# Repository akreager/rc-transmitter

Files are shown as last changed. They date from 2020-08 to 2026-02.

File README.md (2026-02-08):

# RC Transmitter
Open-source design and code for a 3D-printed pistol-grip RC transmitter.

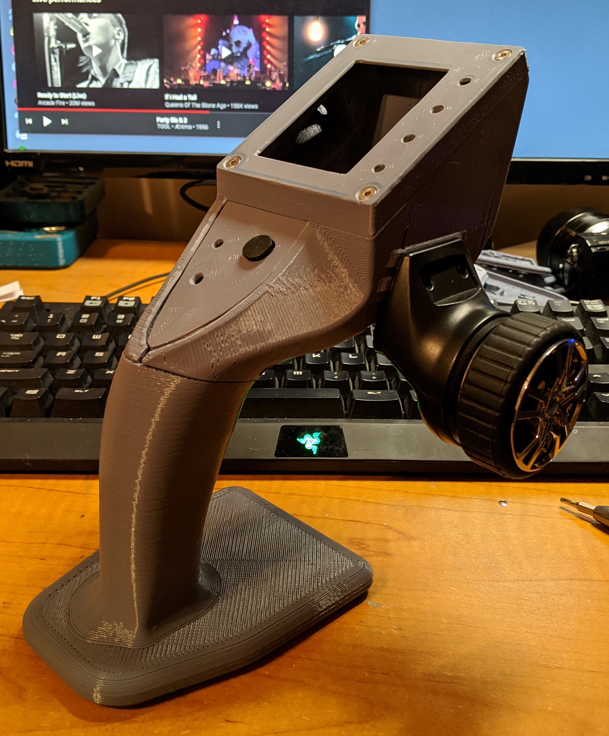
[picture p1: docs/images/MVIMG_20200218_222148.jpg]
Front


## Overview
A general-purpose RC transmitter designed to control multiple vehicles by swapping configuration profiles. Currently used with an RC snowblower and an engineering test rover.

### Features
- **Wireless control** via nRF24L01+ with bidirectional telemetry (acknowledge payloads)
- **Touchscreen UI** on a 240x320 TFT with resistive touch input
- **Live telemetry** display: battery voltage, board temperatures, motor currents
- **Motor stop** (M-Stop) soft button on the touchscreen
- **Joystick input** for throttle and steering

### Planned
- Joystick calibration via touchscreen UI
- Physical button matrix (multiplexed)
- SD card configuration profiles for multi-vehicle support
- Settings/setup menu

## Hardware

### Transmitter
- MCU with dual SPI buses (currently Teensy 4.1)
- [Adafruit 2.8" TFT Touch Breakout](https://www.adafruit.com/product/1770) — ILI9341 display with resistive touchscreen (SPI1)
- nRF24L01+ radio module (SPI0)
- Analog joystick (steering + throttle)

### Receiver ([Rover Test Platform](https://github.com/akreager/roverTest))
- Arduino Mega
- nRF24L01+ radio module
- Basicmicro RoboClaw motor controller

## Project Structure
```
RC Transmitter/
├── main/                 # Transmitter firmware (Arduino IDE)
│   ├── main.ino          # Setup, loop, radio, global state
│   ├── config.h          # Pin assignments, constants, shared types
│   ├── touchInput.ino    # Touch state machine
│   ├── screenManager.ino # Screen transitions and button management
│   └── drawScreens.ino   # Screen drawing and UI updates
├── test_sketches/        # Standalone test/reference sketches
├── stl/                  # 3D printed enclosure files
├── docs/                 # Documentation and images
├── LICENSE               # GPLv3
└── README.md
```

## Pin Assignments (Teensy 4.1)

Active pin mapping for the current build. Also maintained in [Google Sheets](https://docs.google.com/spreadsheets/d/1aVeEQQCFw7_oekkrW9wztb_qrHcS88uQesicZp7ygn0/edit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).

### Display & Touch (SPI1)
| Function | Pin  | Notes |
|---|---|---|
| CLK | D27  | SPI1 clock |
| MISO | D1 | SPI1 data in |
| MOSI | D26  | SPI1 data out |
| TFT CS | D0 | Display chip select |
| TFT DC | D2 | Display data/command |
| Backlight| D3 | PWM brightness control  |
| Touch Y+ | D24  | Analog (A10) |
| Touch X- | D25  | Analog (A11) |
| Touch X+ | D28  | Digital |
| Touch Y- | D29  | Digital |

### Radio (SPI0)
| Function | Pin  | Notes |
|---|---|---|
| SCK | D13  | SPI0 clock (default) |
| MISO | D12  | SPI0 data in (default)  |
| MOSI | D11  | SPI0 data out (default) |
| CE | D9 | |
| CSN | D10  | |

### Inputs
| Function  | Pin  | Notes |
|---|---|---|
| Steering  | D14  | Analog (A0) — wheel input |
| Throttle  | D15  | Analog (A1) — trigger input |
| Joystick X| D17  | Analog (A3) — e.g. chute aim L/R  |
| Joystick Y| D16  | Analog (A2) — e.g. chute aim U/D  |

### Button Matrix (planned)
| Function | Pin  | Notes |
|---|---|---|
| Row A | D30  | Digital |
| Row B | D31  | Digital |
| Row C | D32  | Digital |
| Row D | D33  | Digital |
| Col 1 | D34  | Digital |
| Col 2 | D35  | Digital |

## CAD Source
3D design for the transmitter enclosure is on [OnShape](https://cad.onshape.com/documents/a59ab4c30cdb2f94f953abb2/v/0076fda3a5d6eca29f873ec9/e/06b2695cd32d304990fa8f74).

## Dependencies
Install via Arduino IDE Library Manager:
- [RF24](https://github.com/tmrh20/RF24/) (TMRh20 fork)
- [Adafruit GFX Library](https://github.com/adafruit/Adafruit-GFX-Library)
- [Adafruit ILI9341](https://github.com/adafruit/Adafruit_ILI9341)
- [Adafruit BusIO](https://github.com/adafruit/Adafruit_BusIO)

Bundled with the Teensy board package:
- TouchScreen — included in `{teensy_package}/libraries/TouchScreen`, API-compatible with [Adafruit TouchScreen](https://github.com/adafruit/Adafruit_TouchScreen)

Receiver also requires:
- [RoboClaw Arduino Library](https://github.com/basicmicro/roboclaw_arduino_library)

## Development
This project is developed with assistance from Claude (Anthropic), used for code architecture, refactoring, and documentation.

## License
This project is licensed under the GNU General Public License v3.0 — see [LICENSE](LICENSE) for details.

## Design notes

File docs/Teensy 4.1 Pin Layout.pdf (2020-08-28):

# Teensy 4.1

8/28/2020

Pin (42) | Pins Available Analog In UART I2C SPI PWM Out (18) (8) (3) (3) (27) | Pins Used (66.7%) NRF24 Touch TFT I/O (5/6) (10/11) (13/13)

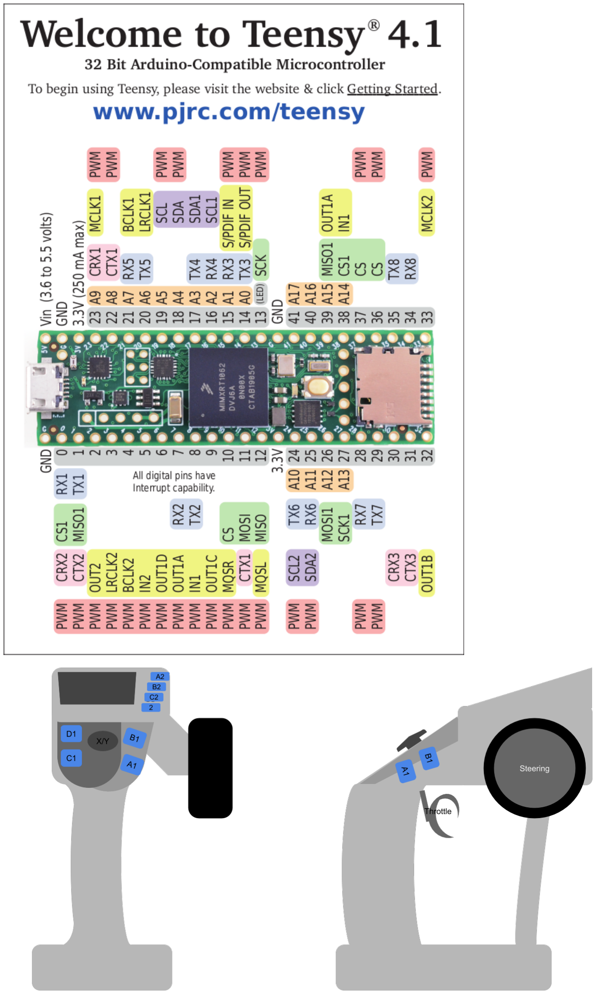
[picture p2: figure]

D0 D1 D2 D3 | RX1 CS1 PWM TX1 MISO1 PWM PWM PWM | TFT_CS MISO D/C LITE
D4 D5 D6 D7 D8 | PWM PWM PWM RX2 PWM TX2 PWM
D9 D10 D11 D12 | PWM CS PWM MOSI PWM MISO PWM | CE CSN MOSI MISO
D13 D14 D15 D16 D17 | SCK PWM A0 TX3 PWM A1 RX3 PWM A2 RX4 SCL1 A3 TX4 SDA1 | SCK Throttle [A] Steering [A] Joystick Y [A] Joystick X [A]
D20 D21 | A6 A7
D18 | A4 | SDA | PWM
D19 | A5 | SCL | PWM

TX5 RX5

D22 | A8 PWM | | Battery Sense [A]
D23 | A9 | PWM
D24 D25 D26 D27 D28 D29 D30 D31 D32 | A10 TX6 SCL2 PWM A11 RX6 SDA2 PWM A12 MOSI1 A13 SCK1 RX7 PWM TX7 PWM | | Y+ [A] X- [A] MOSI CLK X+ [D] Y- [D] A1 [D] B1 [D] C1 [D]
D33 D34 D35 | PWM TX8 RX8 | | D1 [D] A2 [D] B2 [D]
D36 D37 | CS CS | PWM PWM
D38 | A14 | CS1
D39 | A15 | MISO1
D40 D41 | A16 A17 | C2 [D] D2 [D]
| | Pins Needed NRF24 Touch TFT I/O (6) (11) (13)
CE CSN SCK MOSI MISO | CLK MISO MOSI TFT_CS D/C | Throttle [A] Steering [A] Joystick X [A] Joystick Y [A] Battery Sense [A]
IRQ | LITE | A1 [D]
| uSD_CS | B1 [D]
| Y+ [A] X+ [D] Y- [D] X- [A] | C1 [D] D1 [D] A2 [D] B2 [D]
| | C2 [D] D2 [D]

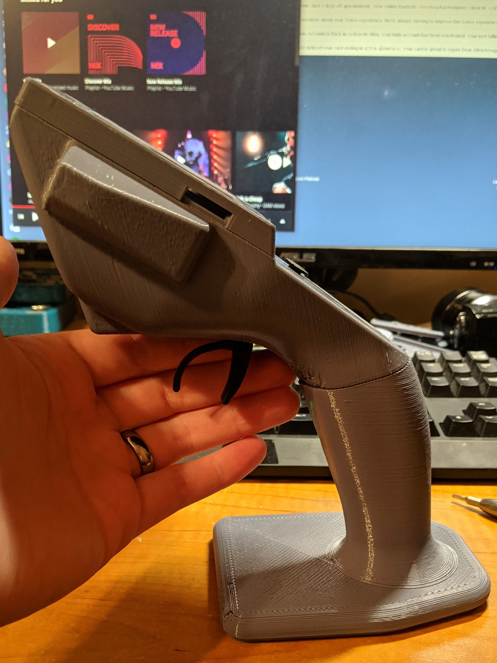
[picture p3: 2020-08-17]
docs/images/MVIMG_20200218_222226.jpg

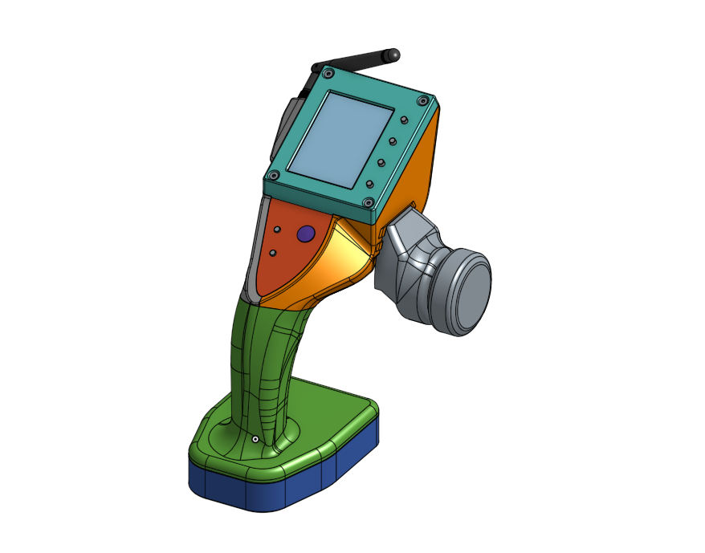
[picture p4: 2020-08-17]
docs/images/Annotation-2020-08-16_211038.png

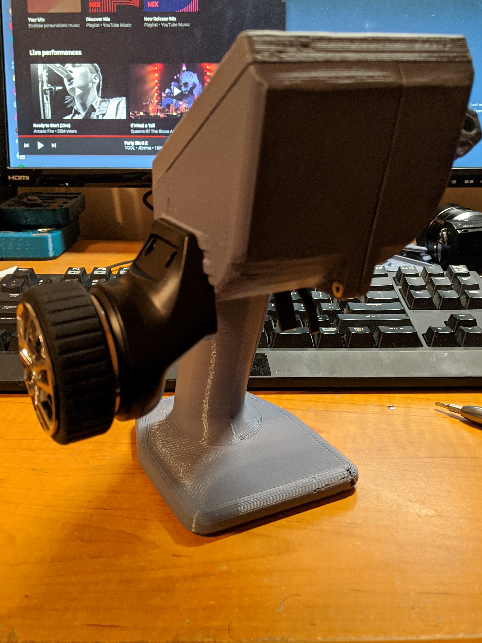
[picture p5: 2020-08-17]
docs/images/MVIMG_20200218_222244.jpg

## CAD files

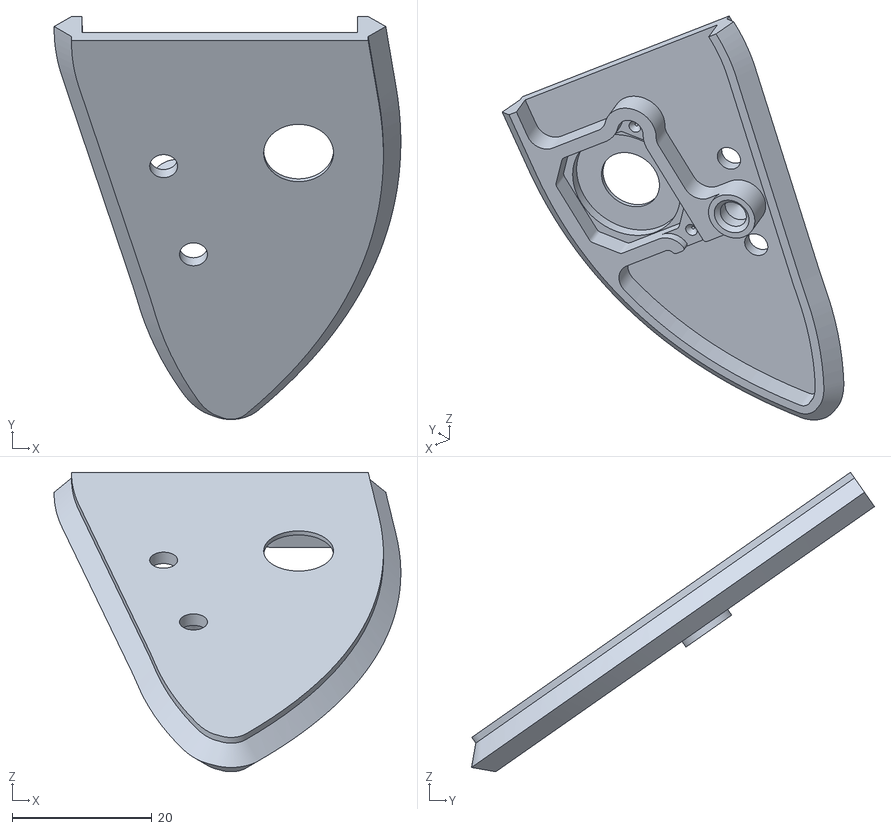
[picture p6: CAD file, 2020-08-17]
stl/Thumb Panel.stl
49.6 x 57.7 x 42.9

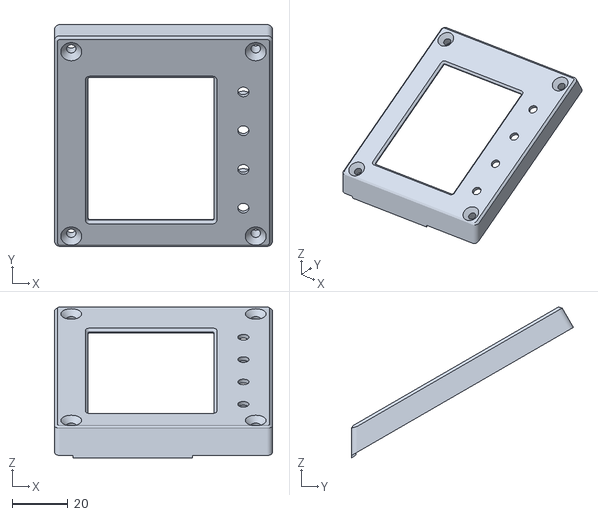
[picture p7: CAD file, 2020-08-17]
stl/LCD Cover.stl
78.0 x 79.4 x 54.0

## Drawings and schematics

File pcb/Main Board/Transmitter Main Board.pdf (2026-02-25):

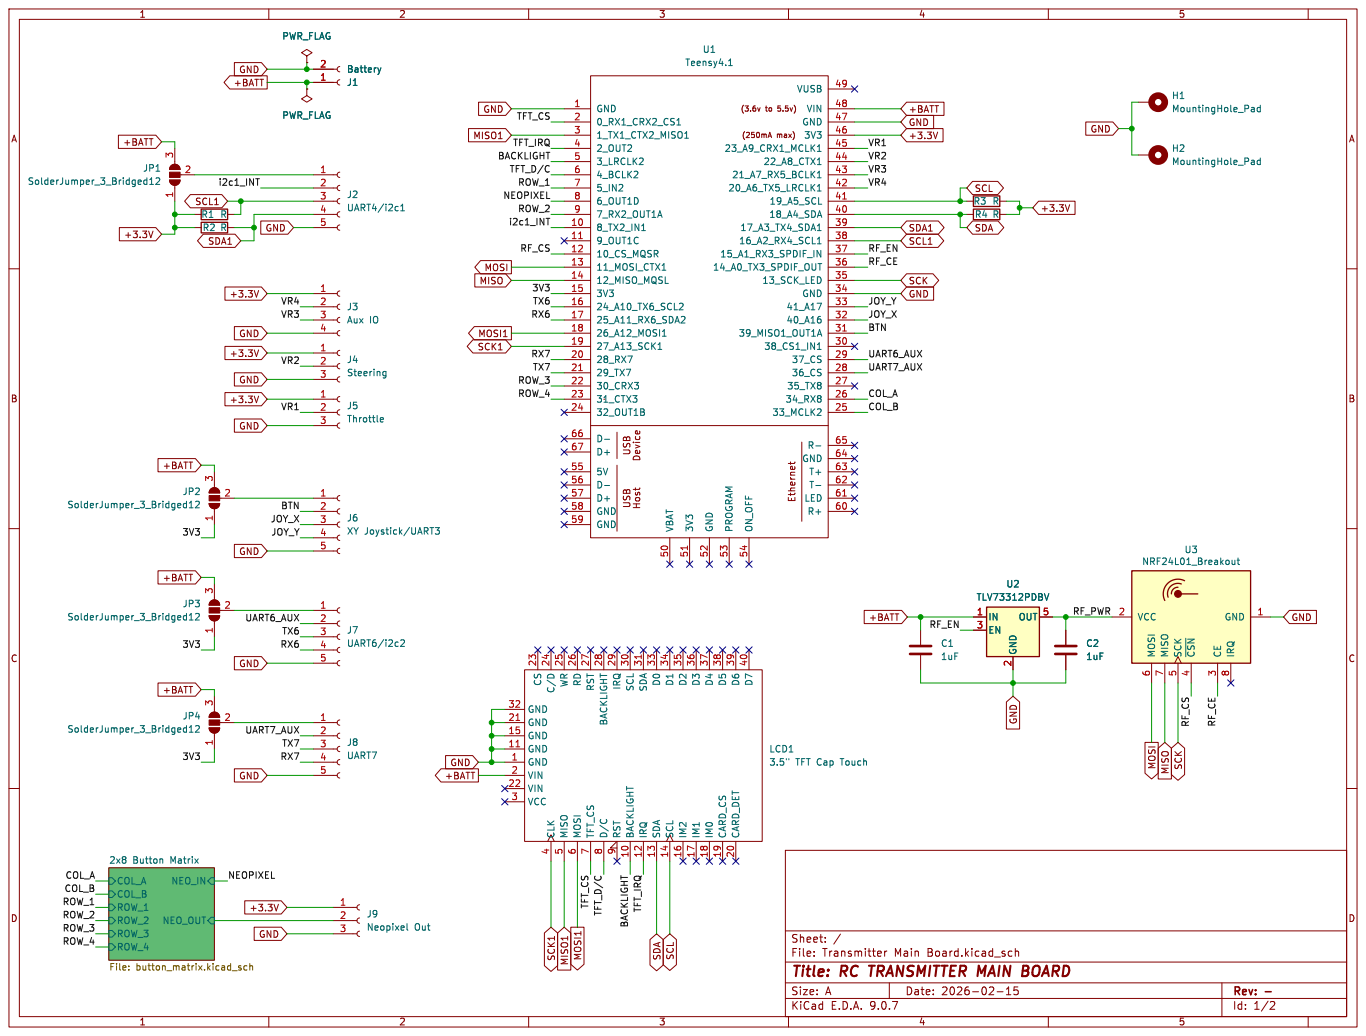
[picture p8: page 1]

9 SCL 30 BACKLIGHT 10 SDA 31 IRQ 12 D0 33 SDA 13 D1 34 SCL 14 D2 35 IM2 16 D3 36 IM1 17 D4 37 IM0 18 D5 38 CARD_CS 19 D6 39 CARD_DET 20 D7 40

Id: 1/2 Title: RC TRANSMITTER MAIN BOARD

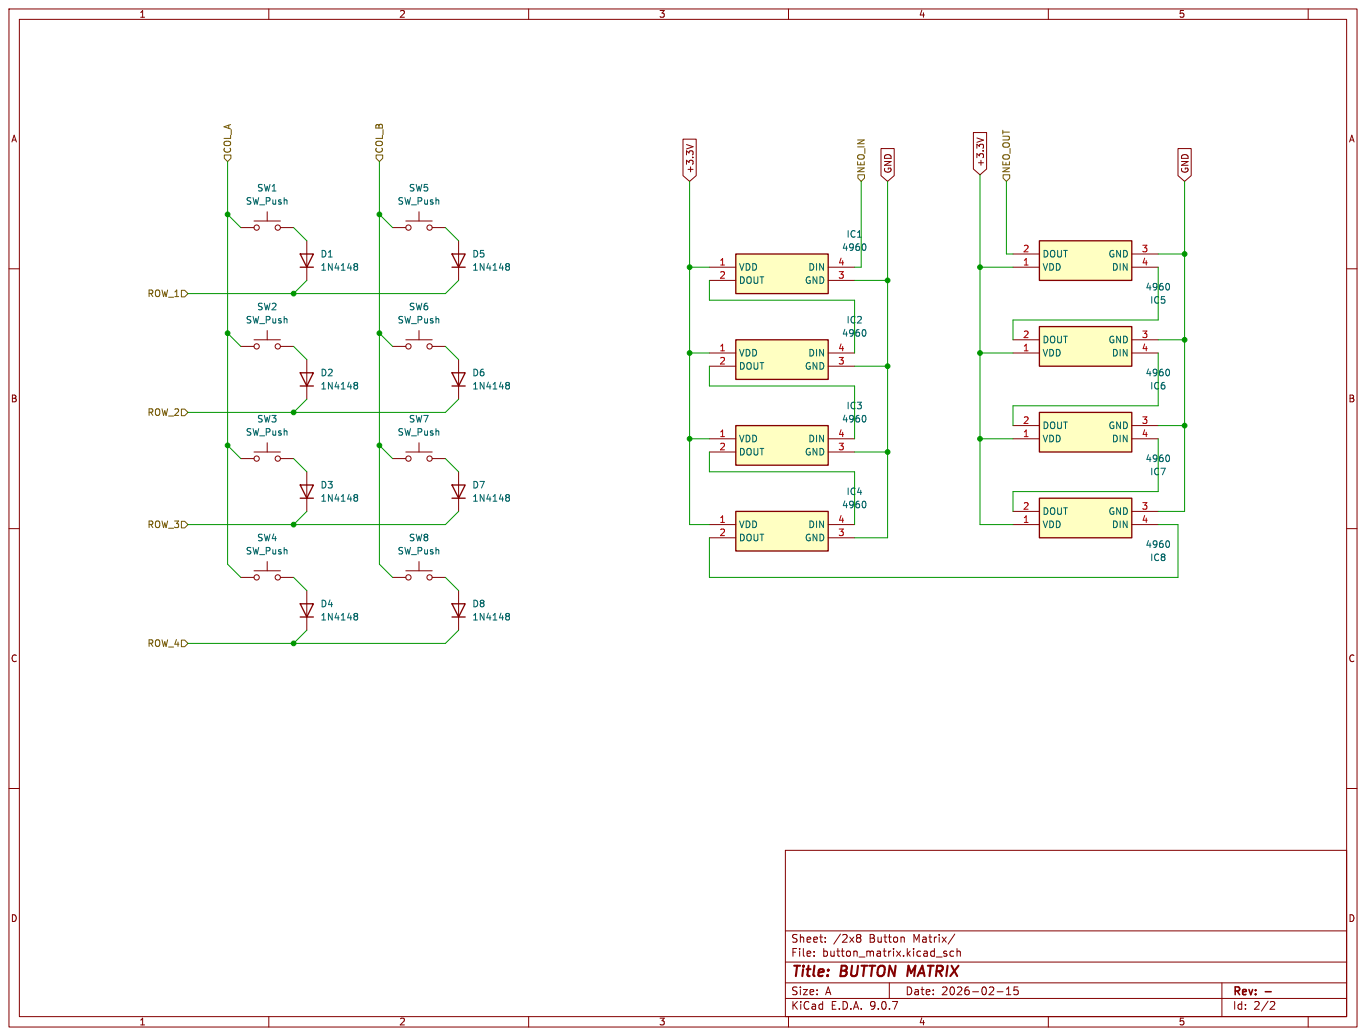
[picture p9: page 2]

Id: 2/2 Title: BUTTON MATRIX

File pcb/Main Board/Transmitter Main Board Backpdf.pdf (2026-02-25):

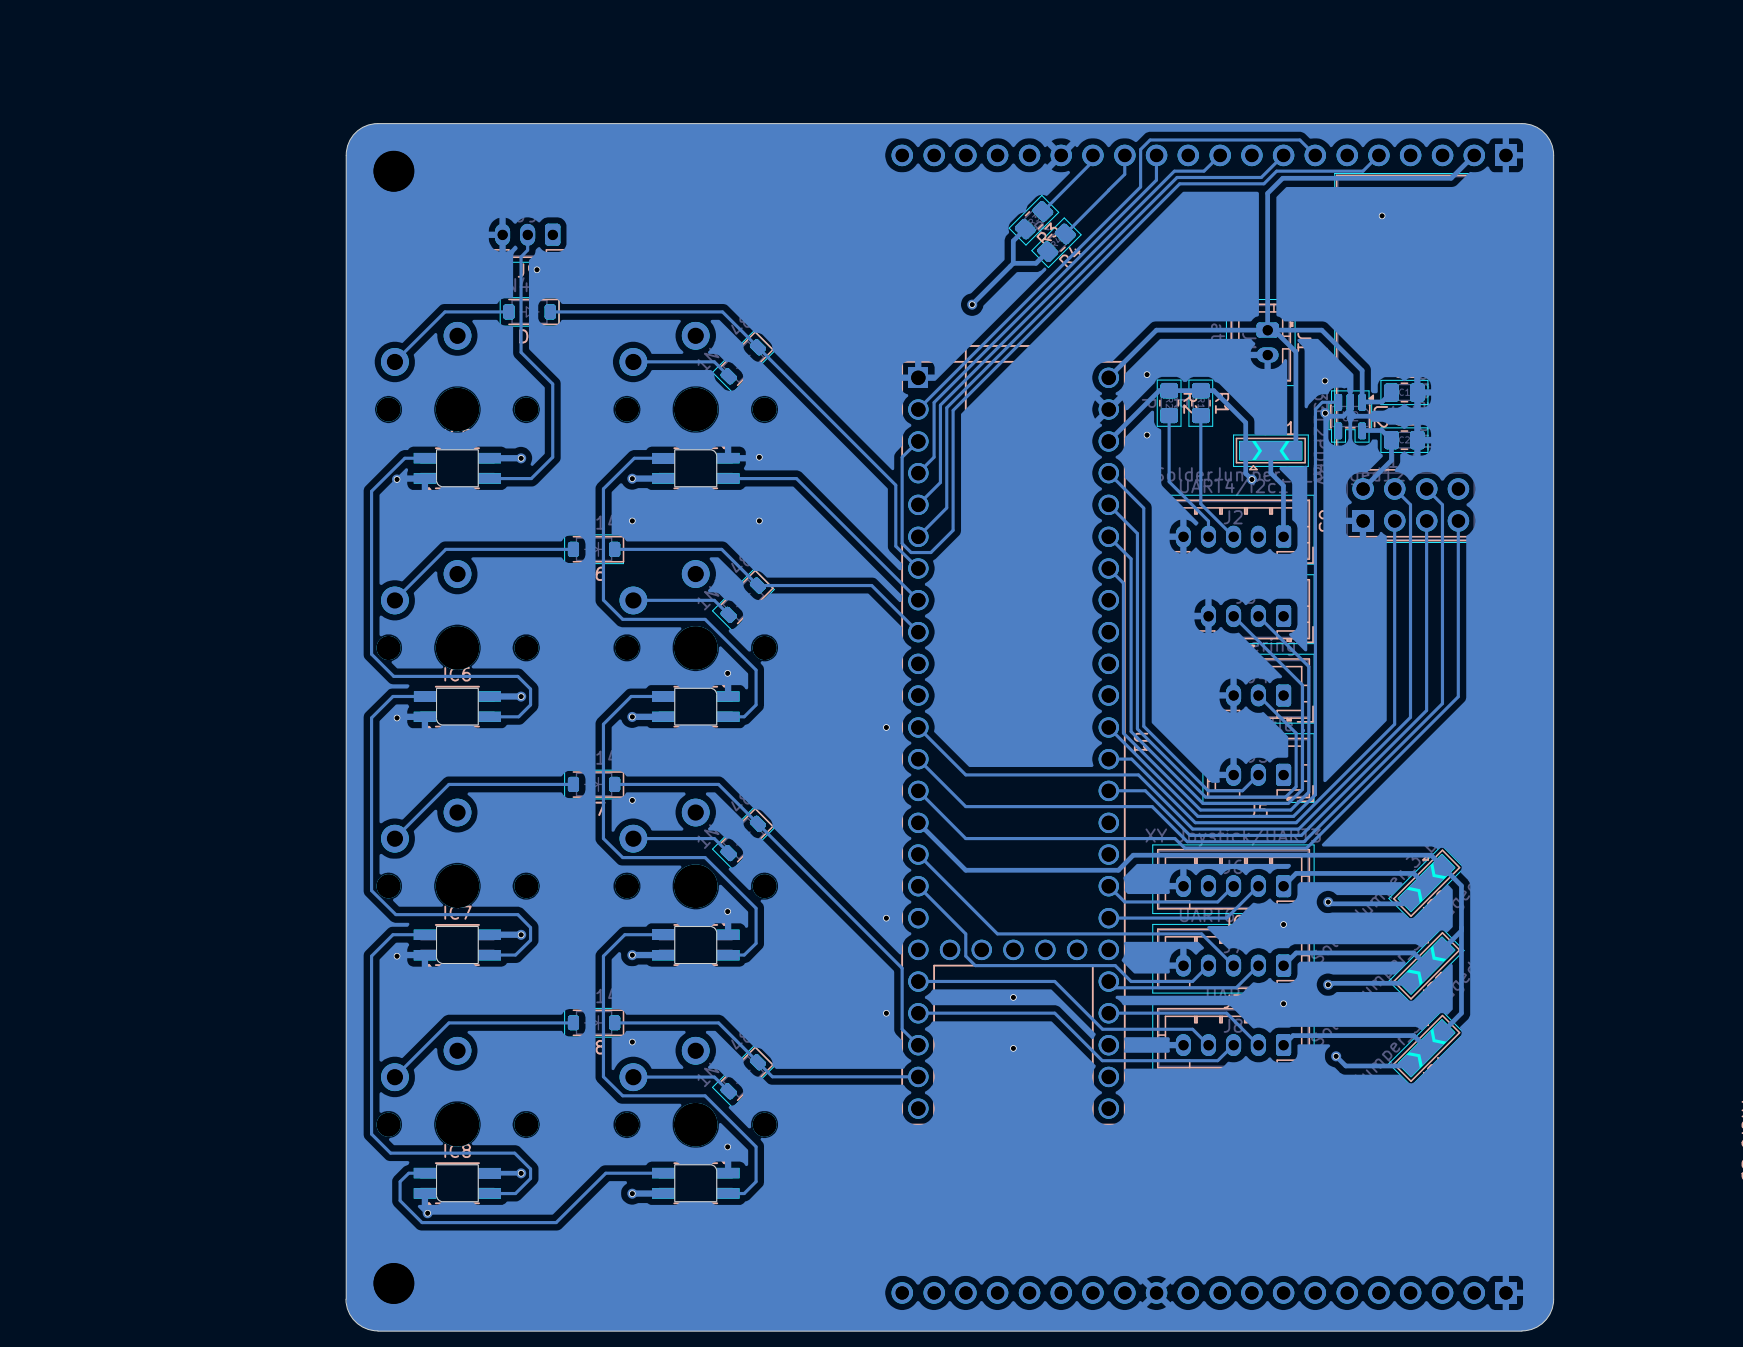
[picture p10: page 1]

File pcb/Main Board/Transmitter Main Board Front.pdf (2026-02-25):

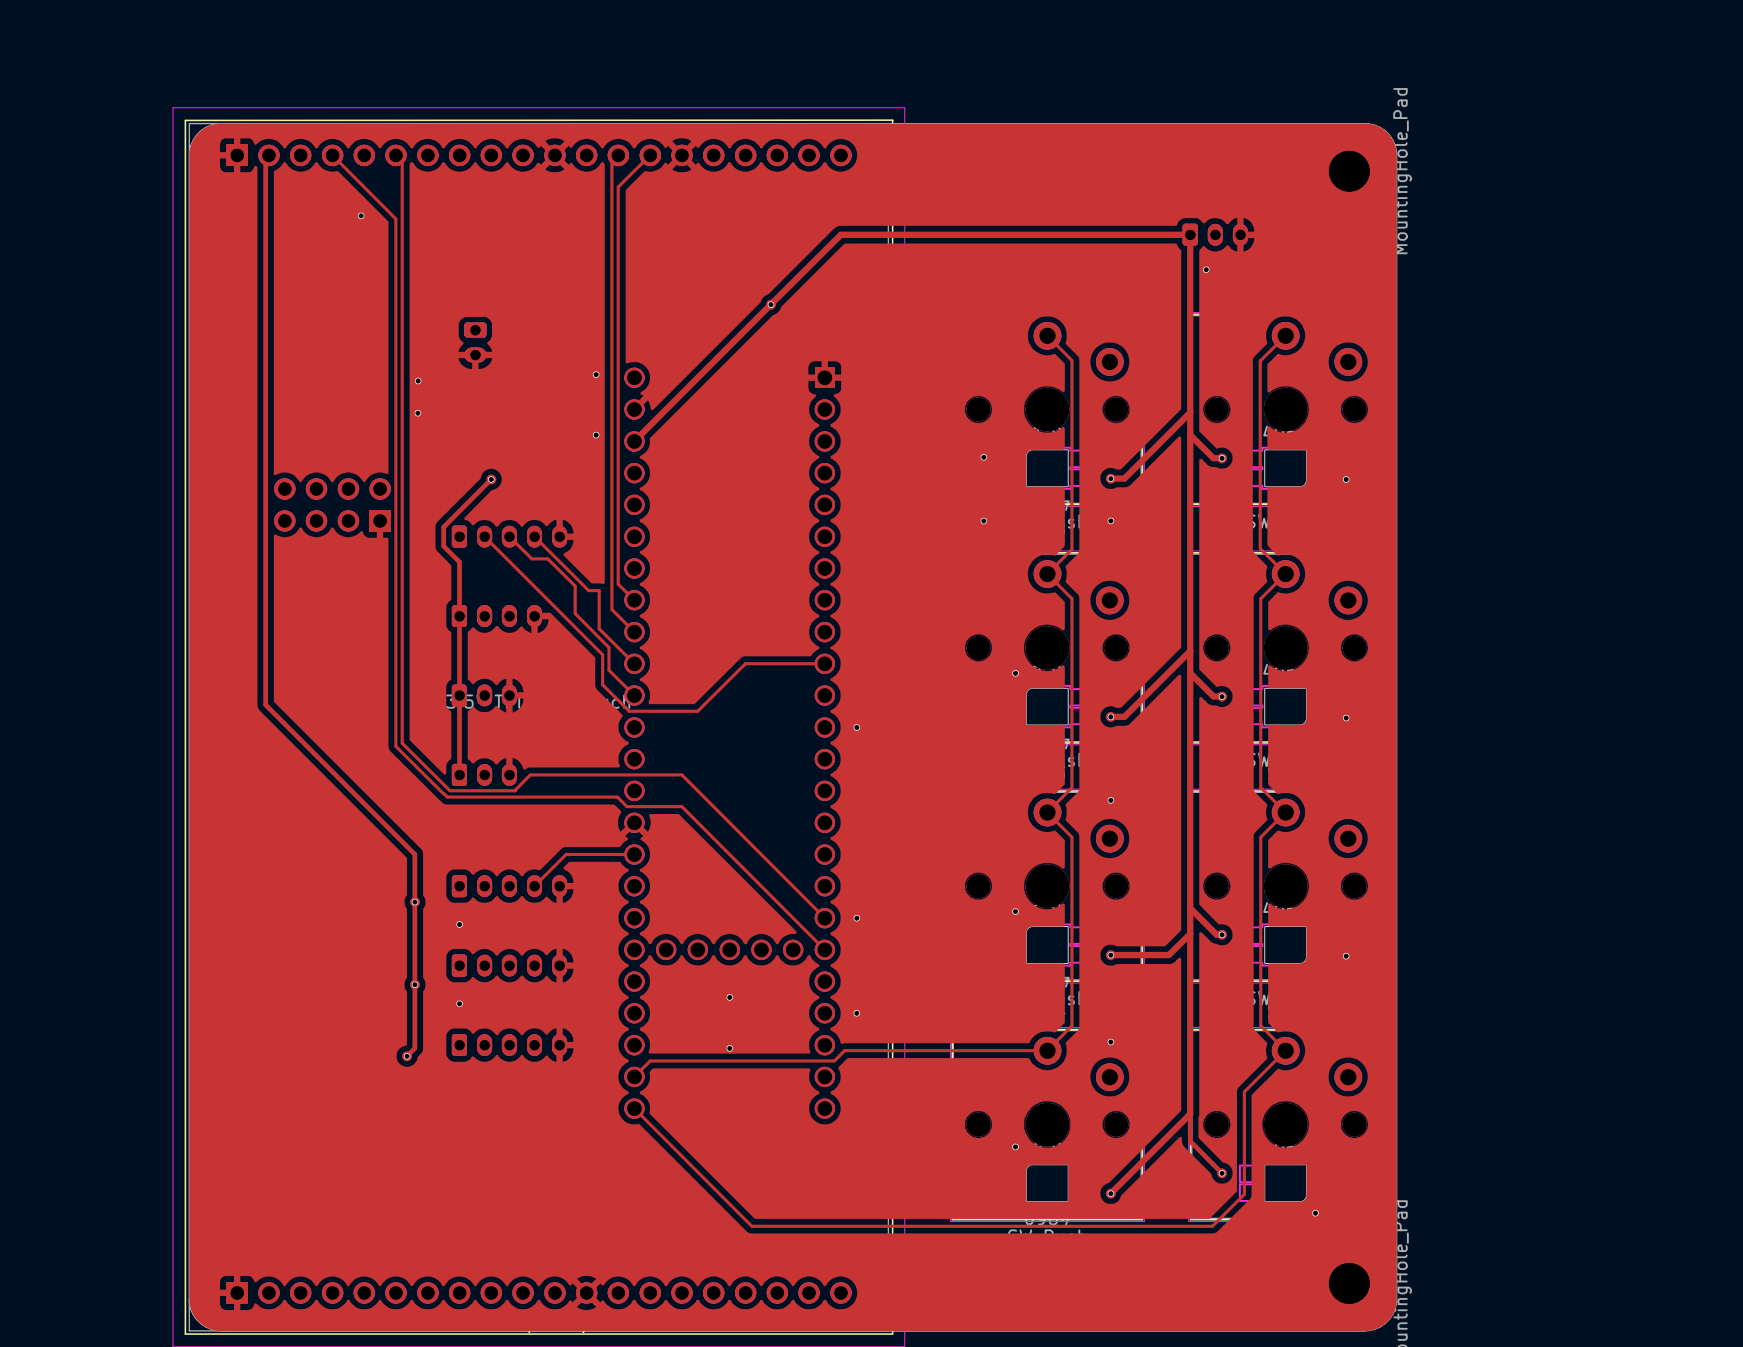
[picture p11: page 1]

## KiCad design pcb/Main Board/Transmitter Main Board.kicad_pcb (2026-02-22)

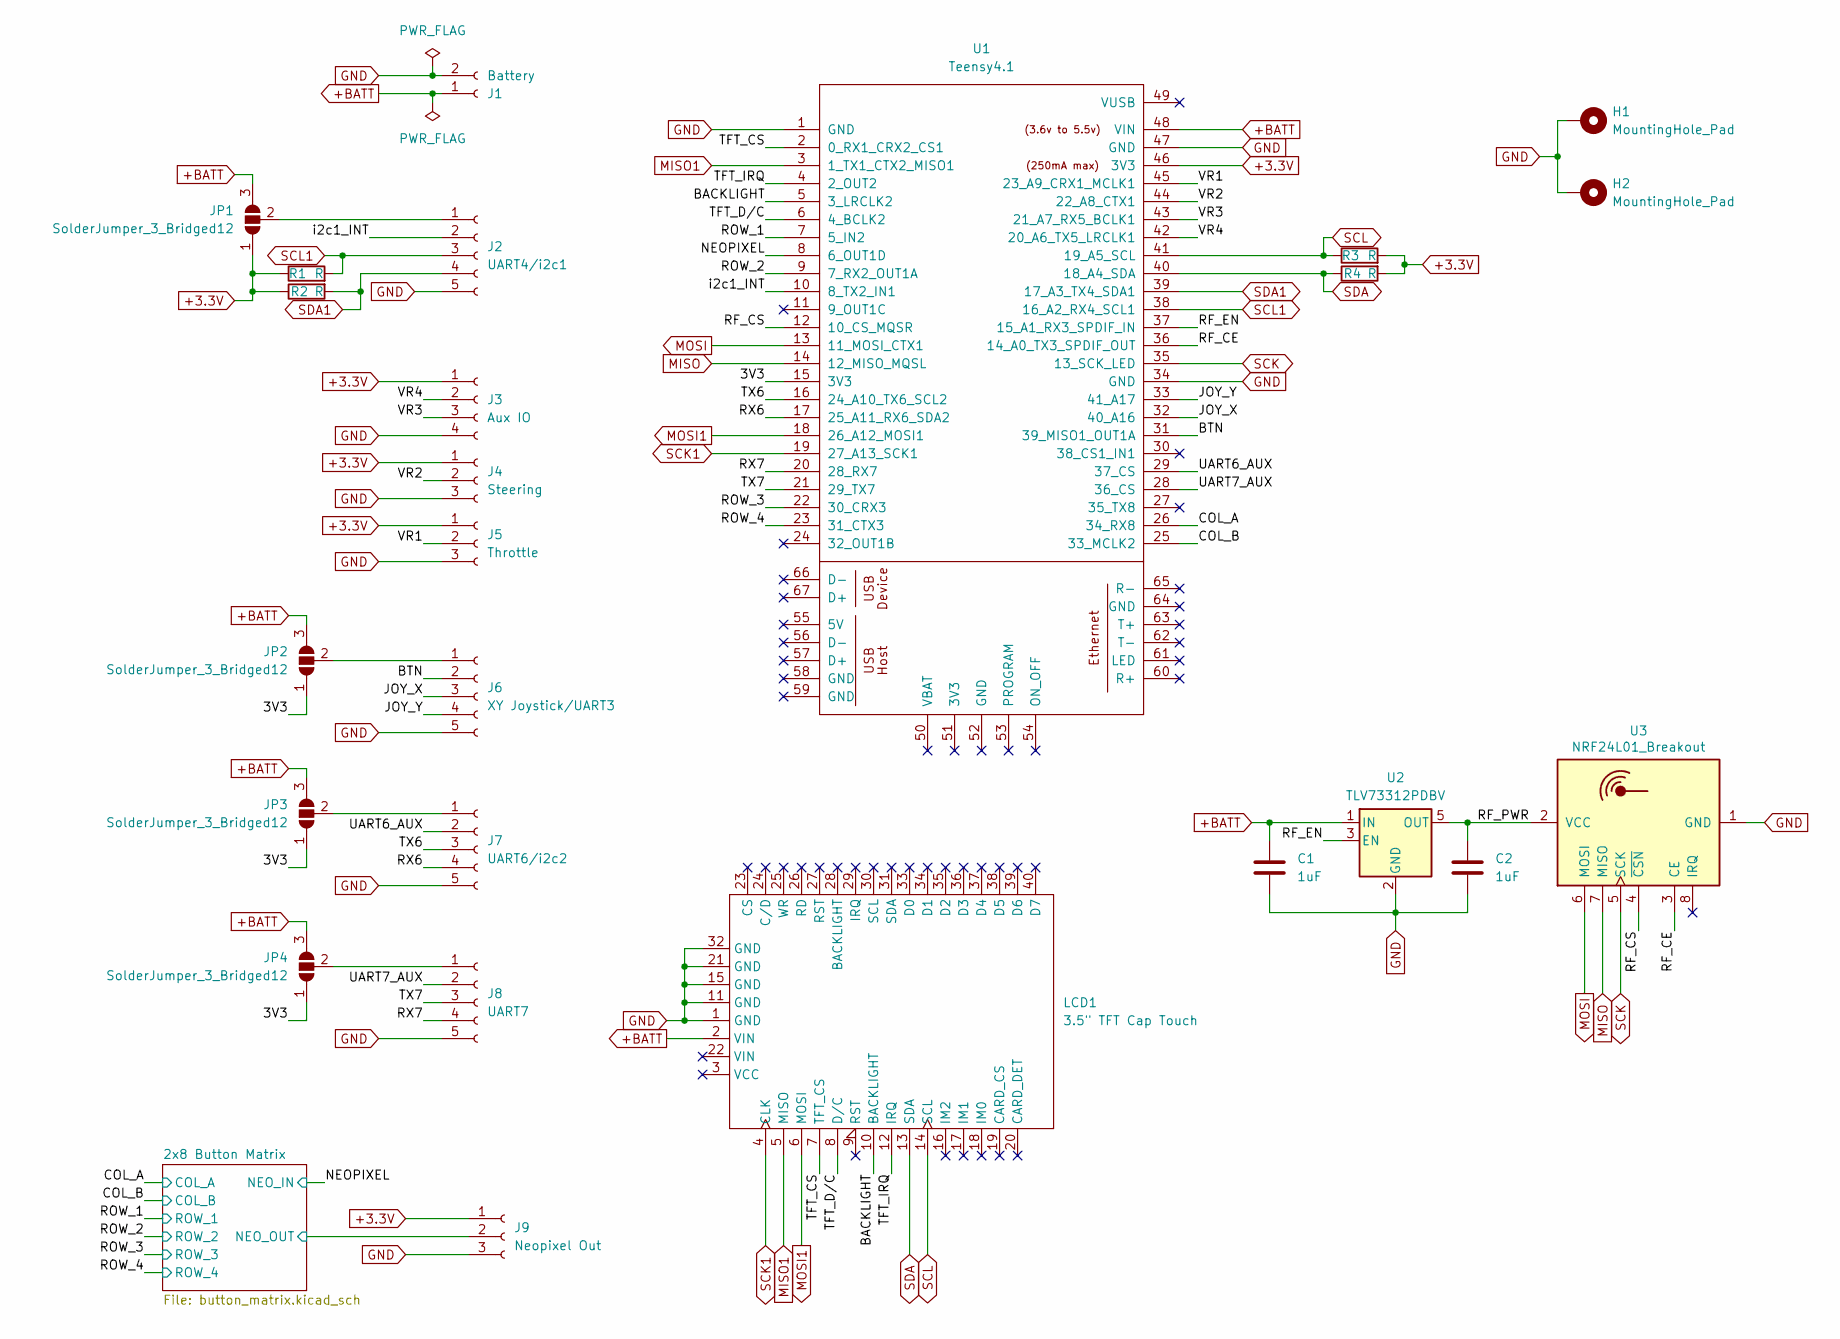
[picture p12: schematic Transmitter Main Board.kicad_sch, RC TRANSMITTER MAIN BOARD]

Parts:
C1, C2: 1uF; C_0805_2012Metric_Pad1.18x1.45mm_HandSolder
H1, H2: MountingHole_Pad; MountingHole_3.2mm_M3_Pad
J1: Battery; JST_PH_B2B-PH-K_1x02_P2.00mm_Vertical
J2: UART4/i2c1; JST_PH_B5B-PH-K_1x05_P2.00mm_Vertical
J3: Aux IO; JST_PH_B4B-PH-K_1x04_P2.00mm_Vertical
J4: Steering; JST_PH_B3B-PH-K_1x03_P2.00mm_Vertical
J5: Throttle; JST_PH_B3B-PH-K_1x03_P2.00mm_Vertical
J6: XY Joystick/UART3; JST_PH_B5B-PH-K_1x05_P2.00mm_Vertical
J7: UART6/i2c2; JST_PH_B5B-PH-K_1x05_P2.00mm_Vertical
J8: UART7; JST_PH_B5B-PH-K_1x05_P2.00mm_Vertical
J9: Neopixel Out; JST_PH_B3B-PH-K_1x03_P2.00mm_Vertical
JP1, JP2, JP3, JP4: SolderJumper_3_Bridged12; SolderJumper-3_P2.0mm_Open_TrianglePad1.0x1.5mm
LCD1: 3.5" TFT Cap Touch; Adafruit_3.5in_480x320_TFT_CapTouch
R1, R2, R3, R4: R; R_0805_2012Metric_Pad1.20x1.40mm_HandSolder
U1: Teensy4.1; Teensy41
U2: TLV73312PDBV; SOT-23-5
U3: NRF24L01_Breakout; nRF24L01_Breakout

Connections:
+3.3V: J3.1, J4.1, J5.1, J9.1, JP1.1 (A), R1.1, R2.1, R3.2, R4.2, U1.46 (3V3); also elsewhere on the board
+BATT: C1.1, J1.1, JP1.3 (B), JP2.3 (B), JP3.3 (B), JP4.3 (B), LCD1.2 (VIN), U1.48 (VIN), U2.1 (IN)
/2x8 Button Matrix/NEO_OUT: J9.2; also elsewhere on the board
/3V3: JP2.1 (A), JP3.1 (A), JP4.1 (A), U1.15 (3V3)
/BACKLIGHT: LCD1.10 (BACKLIGHT), U1.5 (3_LRCLK2)
/BTN: J6.2, U1.31 (39_MISO1_OUT1A)
/COL_A: U1.26 (34_RX8); also elsewhere on the board
/COL_B: U1.25 (33_MCLK2); also elsewhere on the board
/JOY_X: J6.3, U1.32 (40_A16)
/JOY_Y: J6.4, U1.33 (41_A17)
/NEOPIXEL: U1.8 (6_OUT1D); also elsewhere on the board
/RF_CE: U1.36 (14_A0_TX3_SPDIF_OUT), U3.3 (CE)
/RF_CS: U1.12 (10_CS_MQSR), U3.4 (~CSN)
/RF_EN: U1.37 (15_A1_RX3_SPDIF_IN), U2.3 (EN)
/RF_PWR: C2.1, U2.5 (OUT), U3.2 (VCC)
/ROW_1: U1.7 (5_IN2); also elsewhere on the board
/ROW_2: U1.9 (7_RX2_OUT1A); also elsewhere on the board
/ROW_3: U1.22 (30_CRX3); also elsewhere on the board
/ROW_4: U1.23 (31_CTX3); also elsewhere on the board
/RX6: J7.4, U1.17 (25_A11_RX6_SDA2)
/RX7: J8.4, U1.20 (28_RX7)
/TFT_CS: LCD1.7 (TFT_CS), U1.2 (0_RX1_CRX2_CS1)
/TFT_D/C: LCD1.8 (D/C), U1.6 (4_BCLK2)
/TFT_IRQ: LCD1.12 (IRQ), U1.4 (2_OUT2)
/TX6: J7.3, U1.16 (24_A10_TX6_SCL2)
/TX7: J8.3, U1.21 (29_TX7)
/UART6_AUX: J7.2, U1.29 (37_CS)
/UART7_AUX: J8.2, U1.28 (36_CS)
/VR1: J5.2, U1.45 (23_A9_CRX1_MCLK1)
/VR2: J4.2, U1.44 (22_A8_CTX1)
/VR3: J3.3, U1.43 (21_A7_RX5_BCLK1)
/VR4: J3.2, U1.42 (20_A6_TX5_LRCLK1)
/i2c1_INT: J2.2, U1.10 (8_TX2_IN1)
GND: C1.2, C2.2, H1.1, H2.1, J1.2, J2.5, J3.4, J4.3, J5.3, J6.5, J7.5, J8.5, J9.3, LCD1.1 (GND), LCD1.11 (GND), LCD1.15 (GND), LCD1.21 (GND), LCD1.32 (GND), U1.1 (GND), U1.34 (GND), U1.47 (GND), U2.2 (GND), U3.1 (GND); also elsewhere on the board
MISO: U1.14 (12_MISO_MQSL), U3.7 (MISO)
MISO1: LCD1.5 (MISO), U1.3 (1_TX1_CTX2_MISO1)
MOSI: U1.13 (11_MOSI_CTX1), U3.6 (MOSI)
MOSI1: LCD1.6 (MOSI), U1.18 (26_A12_MOSI1)
unnamed: J2.1, JP1.2 (C)
unnamed: J6.1, JP2.2 (C)
unnamed: J7.1, JP3.2 (C)
unnamed: J8.1, JP4.2 (C)
SCK: U1.35 (13_SCK_LED), U3.5 (SCK)
SCK1: LCD1.4 (CLK), U1.19 (27_A13_SCK1)
SCL: LCD1.14 (SCL), R3.1, U1.41 (19_A5_SCL)
SCL1: J2.3, R1.2, U1.38 (16_A2_RX4_SCL1)
SDA: LCD1.13 (SDA), R4.1, U1.40 (18_A4_SDA)
SDA1: J2.4, R2.2, U1.39 (17_A3_TX4_SDA1)

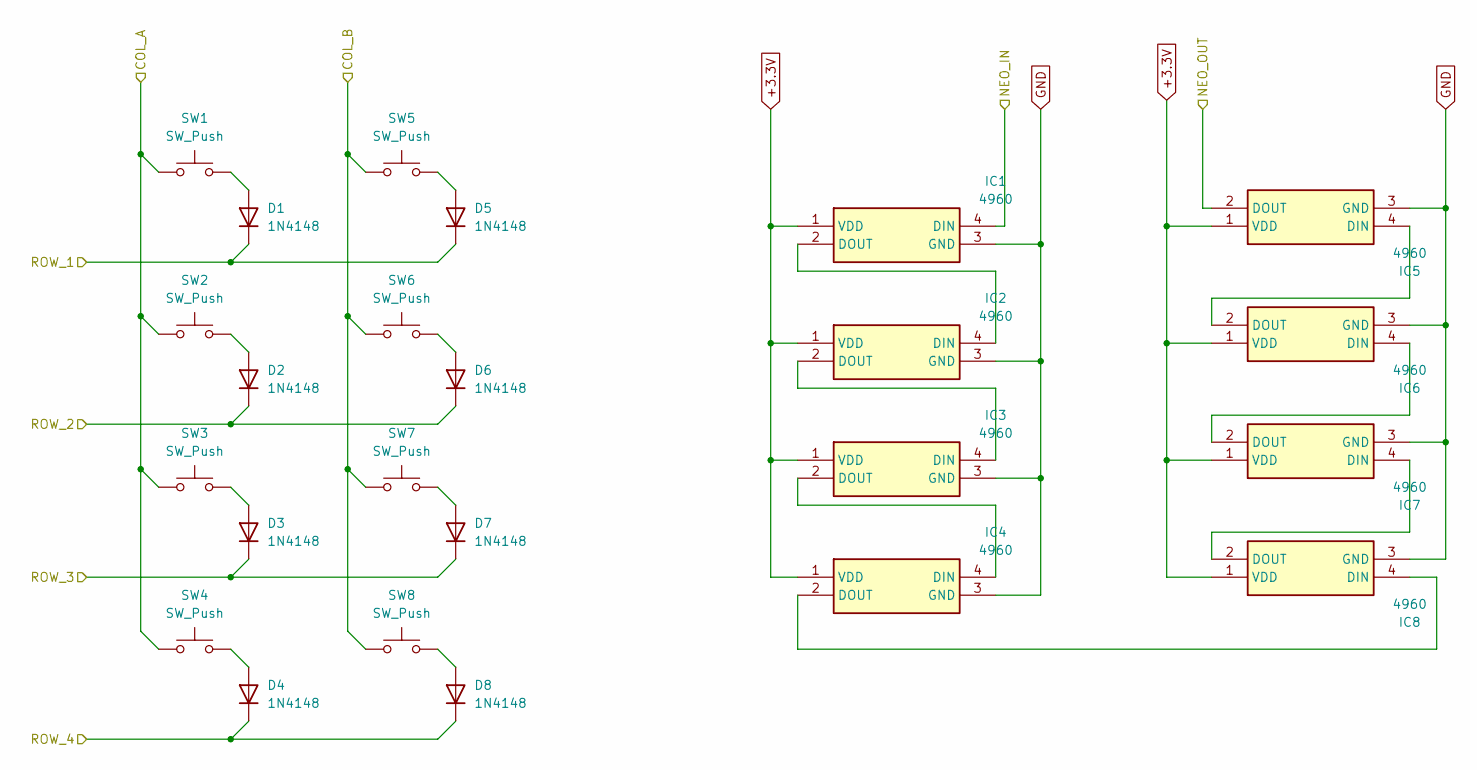
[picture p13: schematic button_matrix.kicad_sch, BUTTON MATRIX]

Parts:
D1, D2, D3, D4, D5, D6, D7, D8: 1N4148; D_SOD-123
IC1, IC2, IC3, IC4, IC5, IC6, IC7, IC8: 4960; 4960_ADA; Mouser Part Number 485-4960
SW1, SW2, SW3, SW4, SW5, SW6, SW7, SW8: SW_Push; SW_Kailh_Choc_V1

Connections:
+3.3V: IC1.1 (VDD), IC2.1 (VDD), IC3.1 (VDD), IC4.1 (VDD), IC5.1 (VDD), IC6.1 (VDD), IC7.1 (VDD), IC8.1 (VDD); also elsewhere on the board
/2x8 Button Matrix/NEO_OUT: IC5.2 (DOUT); also elsewhere on the board
/COL_A: SW1.1, SW2.1, SW3.1, SW4.1; also elsewhere on the board
/COL_B: SW5.1, SW6.1, SW7.1, SW8.1; also elsewhere on the board
/NEOPIXEL: IC1.4 (DIN); also elsewhere on the board
/ROW_1: D1.1 (K), D5.1 (K); also elsewhere on the board
/ROW_2: D2.1 (K), D6.1 (K); also elsewhere on the board
/ROW_3: D3.1 (K), D7.1 (K); also elsewhere on the board
/ROW_4: D4.1 (K), D8.1 (K); also elsewhere on the board
GND: IC1.3 (GND), IC2.3 (GND), IC3.3 (GND), IC4.3 (GND), IC5.3 (GND), IC6.3 (GND), IC7.3 (GND), IC8.3 (GND); also elsewhere on the board
unnamed: D1.2 (A), SW1.2
unnamed: D2.2 (A), SW2.2
unnamed: D3.2 (A), SW3.2
unnamed: D4.2 (A), SW4.2
unnamed: D5.2 (A), SW5.2
unnamed: D6.2 (A), SW6.2
unnamed: D7.2 (A), SW7.2
unnamed: D8.2 (A), SW8.2
unnamed: IC1.2 (DOUT), IC2.4 (DIN)
unnamed: IC2.2 (DOUT), IC3.4 (DIN)
unnamed: IC3.2 (DOUT), IC4.4 (DIN)
unnamed: IC4.2 (DOUT), IC8.4 (DIN)
unnamed: IC5.4 (DIN), IC6.2 (DOUT)
unnamed: IC6.4 (DIN), IC7.2 (DOUT)
unnamed: IC7.4 (DIN), IC8.2 (DOUT)

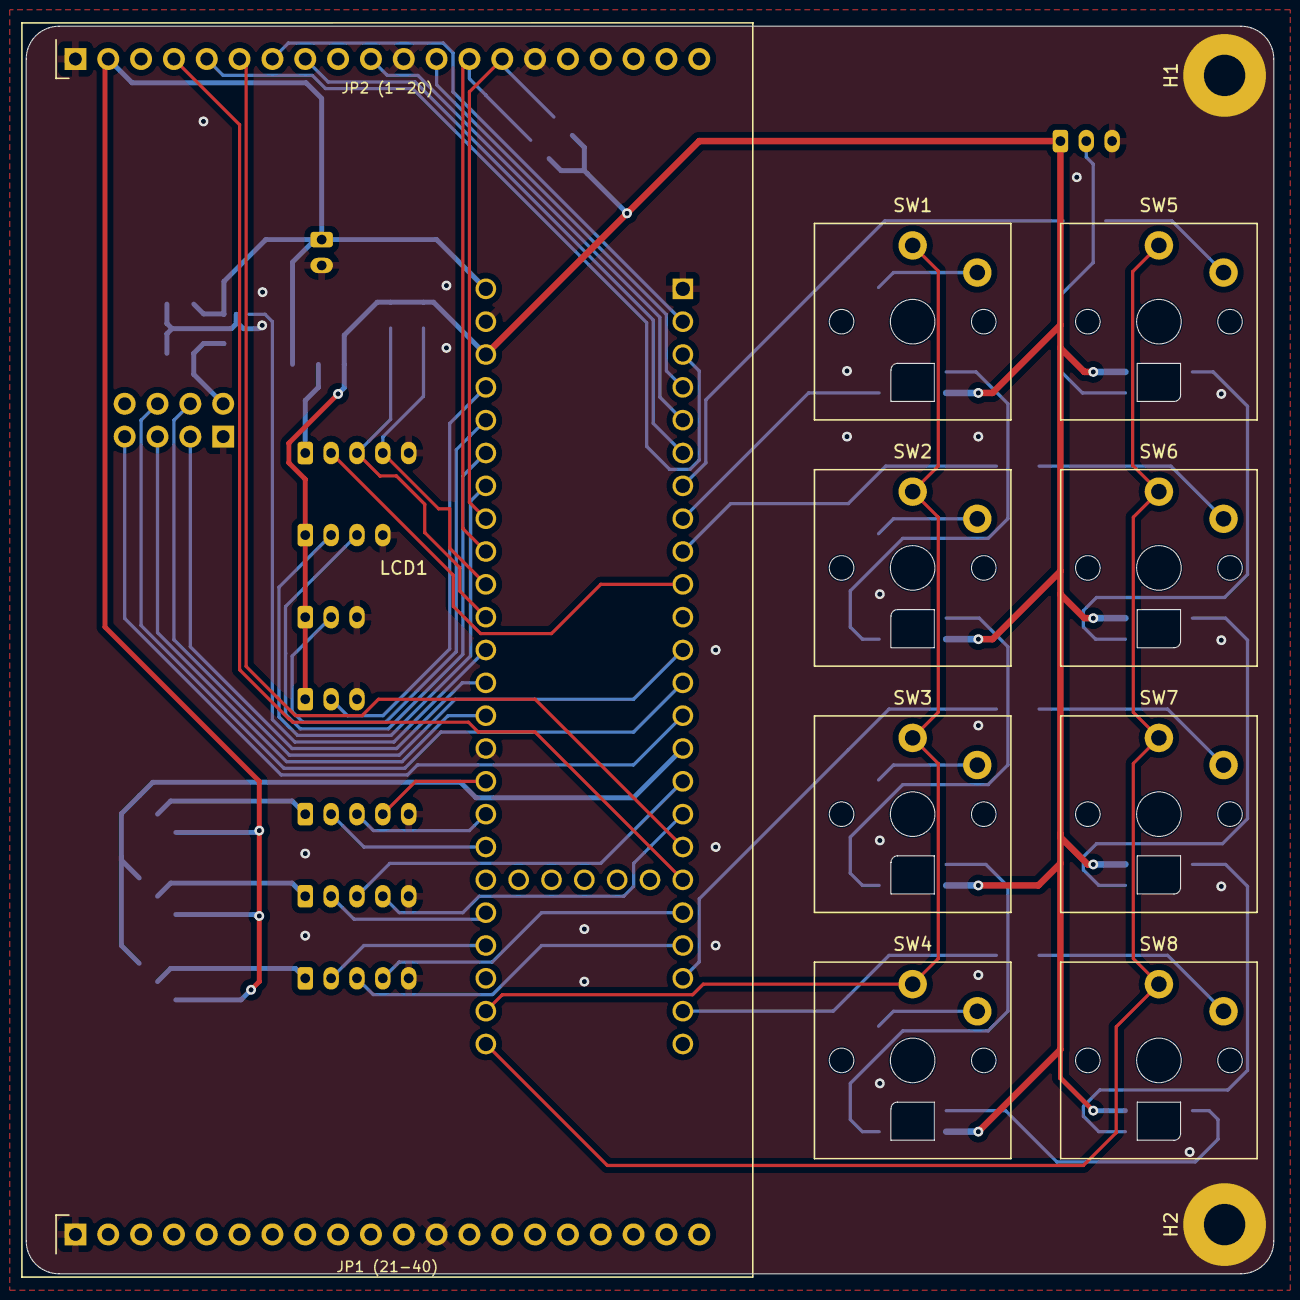
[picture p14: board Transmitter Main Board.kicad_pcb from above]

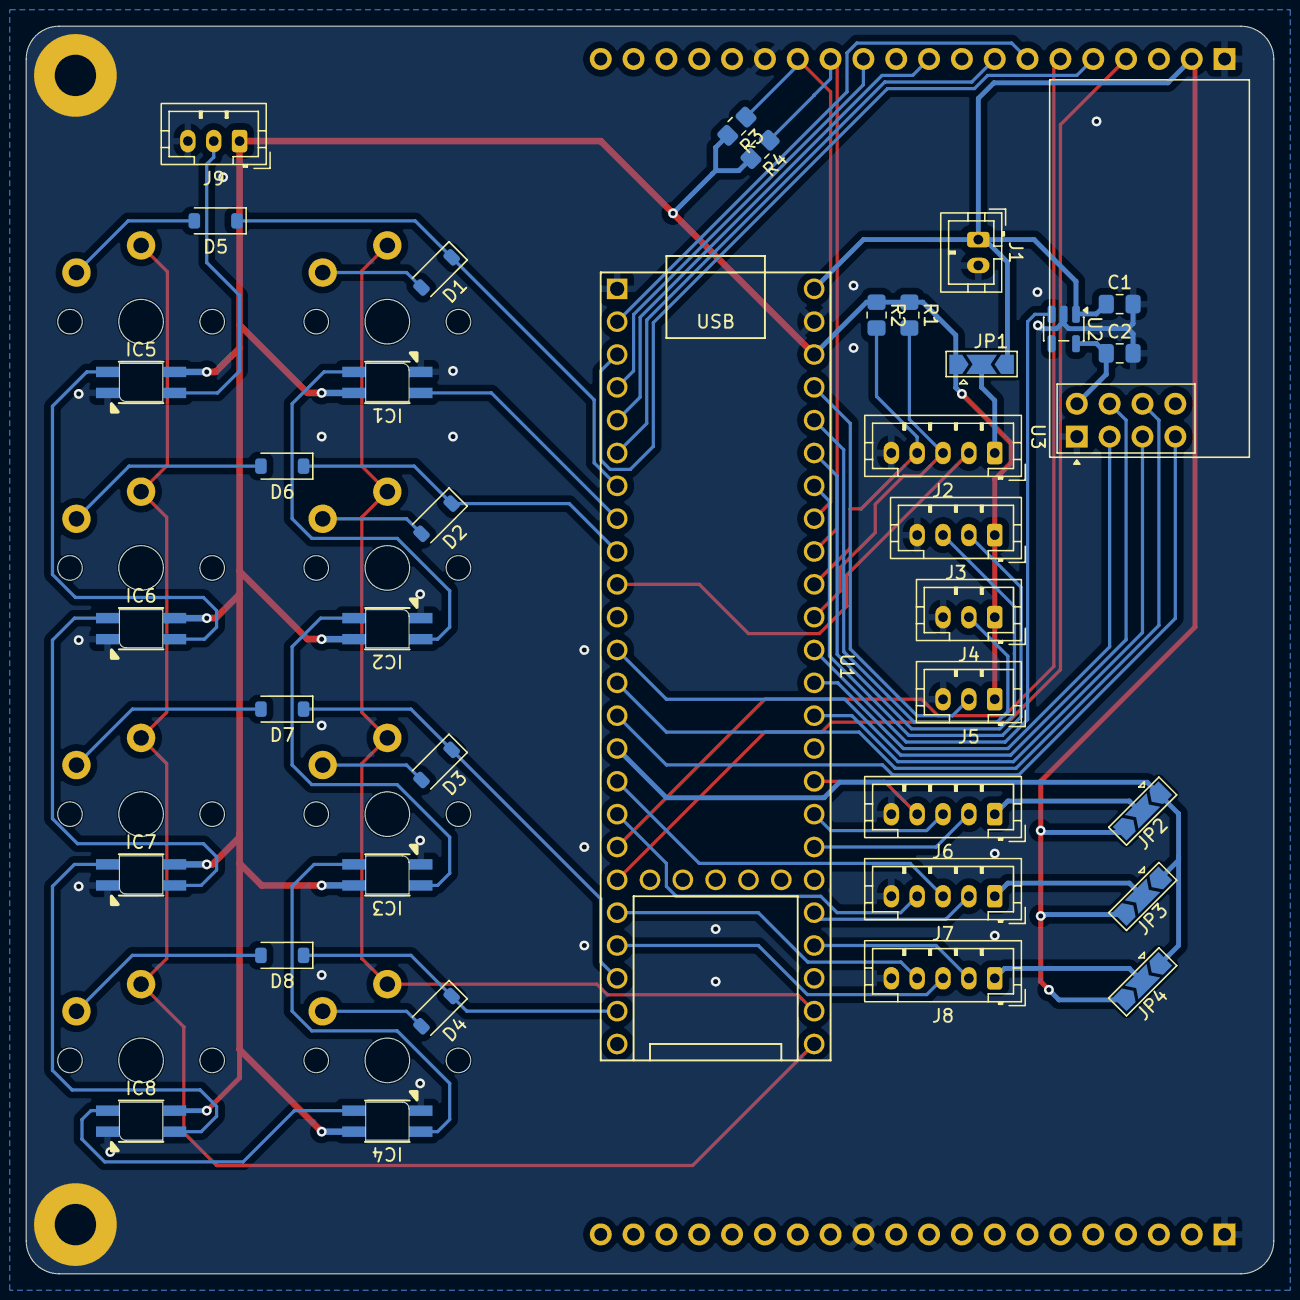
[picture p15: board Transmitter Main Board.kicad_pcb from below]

Board: 2 copper layers, 96.5 x 96.5 mm, 49 parts (30 on the bottom side), 63 nets.

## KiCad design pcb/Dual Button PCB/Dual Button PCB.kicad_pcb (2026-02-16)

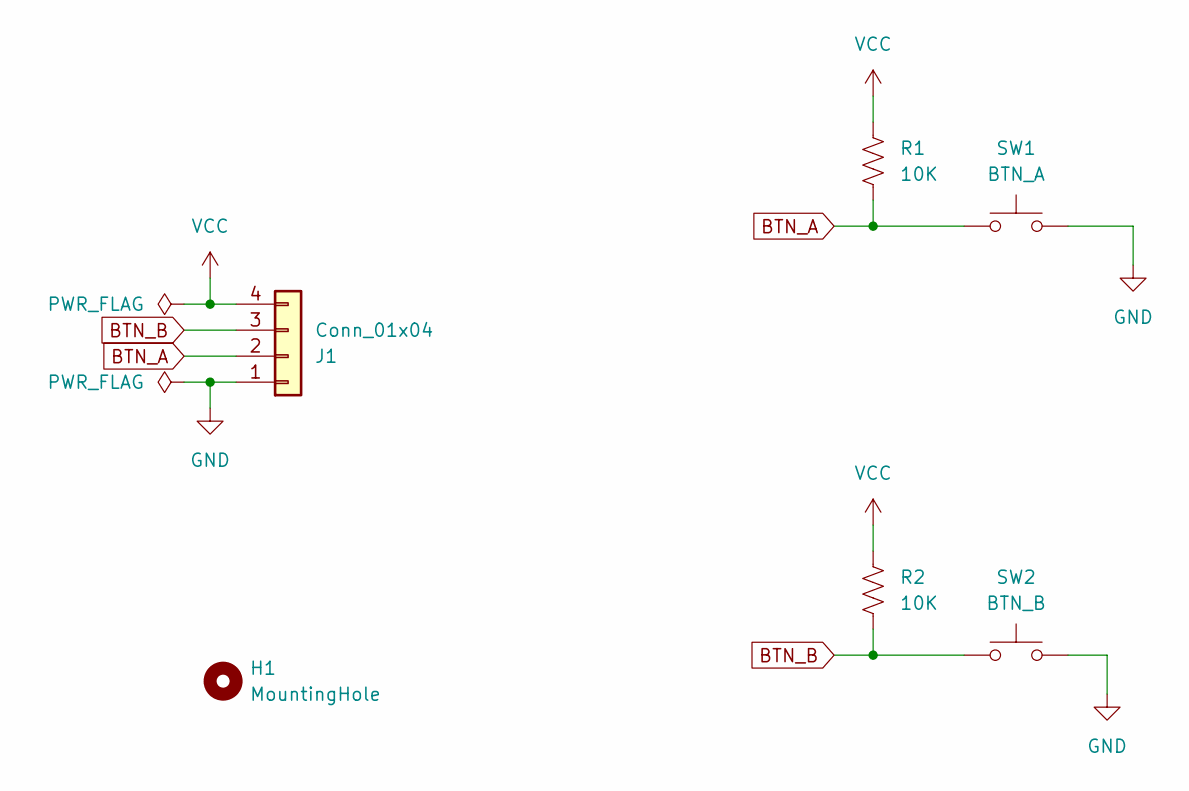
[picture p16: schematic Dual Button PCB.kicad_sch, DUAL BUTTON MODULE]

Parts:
H1: MountingHole; MountingHole_3.5mm
J1: Conn_01x04; JST_XH_B4B-XH-A_1x04_P2.50mm_Vertical
R1, R2: 10K; R_0805_2012Metric_Pad1.20x1.40mm_HandSolder
SW1: BTN_A; SW_PUSH_6mm_H5mm
SW2: BTN_B; SW_PUSH_6mm_H5mm

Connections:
BTN_A: J1.2, R1.1, SW1.1
BTN_B: J1.3, R2.2, SW2.2
GND: J1.1, SW1.2, SW2.1
VCC: J1.4, R1.2, R2.1

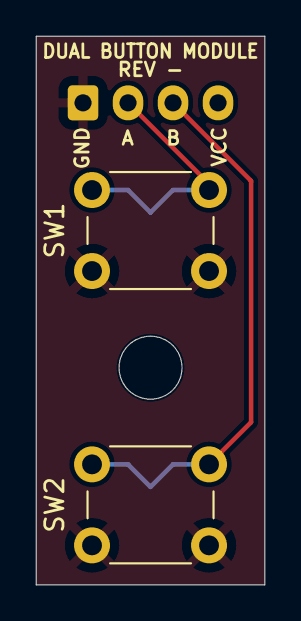
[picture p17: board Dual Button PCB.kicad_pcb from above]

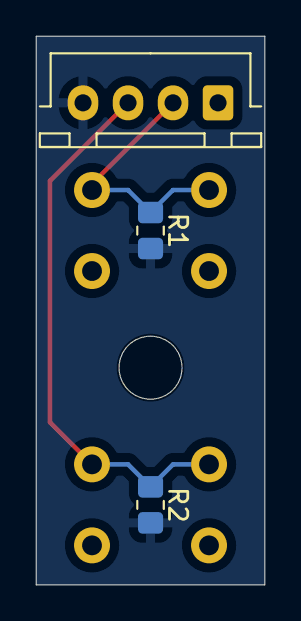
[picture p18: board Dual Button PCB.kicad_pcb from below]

Board: 2 copper layers, 12.7 x 30.5 mm, 6 parts (3 on the bottom side), 4 nets.

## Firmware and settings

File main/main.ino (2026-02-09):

/*
  RC Transmitter - Teensy 4.1
  
  Wireless RC transmitter with touchscreen UI.
  Sends joystick data via nRF24L01 and displays telemetry
  received back from the rover via acknowledge payloads.

  Hardware:
    - Teensy 4.1
    - Adafruit 2.8" TFT Touch Breakout (https://www.adafruit.com/product/1770)
    - nRF24L01+ radio (SPI0)
    - Analog joystick (steering + throttle)
    - RoboClaw motor controller on rover side

  Libraries:
    - RF24 (TMRh20 fork)
    - Adafruit GFX + ILI9341
    - Adafruit TouchScreen

  Developed with assistance from Claude (Anthropic).
*/

#include <SPI.h>
#include <nRF24L01.h>
#include <RF24.h>
#include <Adafruit_GFX.h>
#include <Adafruit_ILI9341.h>
#include <TouchScreen.h>
#include "config.h"

// ============================================================
// HARDWARE OBJECTS
// ============================================================
RF24 radio(CE_PIN, CSN_PIN);
const byte address[6] = "00001";

Adafruit_ILI9341 tft = Adafruit_ILI9341(&SPI1, TFT_DC, TFT_CS);
TouchScreen ts = TouchScreen(XP, YP, XM, YM, TS_RESISTANCE);

// ============================================================
// RADIO DATA STRUCTURES
// These must match the receiver's struct definitions exactly!
// ============================================================
struct dataPackage {
  byte throttle;
  byte steering;
  bool data_motor_stop;
};
dataPackage data;

struct ackPackage {
  byte highBatt;
  byte lowBatt;
  byte highTemp1;
  byte lowTemp1;
  byte highTemp2;
  byte lowTemp2;
  byte highIM1;
  byte lowIM1;
  byte highIM2;
  byte lowIM2;
  bool ack_motor_stop;
};
ackPackage ack;

// ============================================================
// ANALOG INPUT STATE
// ============================================================
// Index 0 = A0 (steering pin), Index 1 = A1 (throttle pin)
// Vehicle config maps these to functions.
AnalogCalData analogInputs[NUM_ANALOG_INPUTS] = {
  { JOY_STEERING, 512, 0, 1023, ACAL_DEFAULT_DEADZONE, false },
  { JOY_THROTTLE, 512, 0, 1023, ACAL_DEFAULT_DEADZONE, false }
};

// Active calibration state
int aCalInputIdx = -1;                // Which input is being calibrated (-1 = none)
AnalogCalStep aCalStep = ACAL_IDLE;

// ============================================================
// TELEMETRY STATE
// ============================================================
unsigned int rawBatt = 0;
unsigned int rawTemp1 = 0;
unsigned int rawTemp2 = 0;
int rawCurrentMotor1 = 0;
int rawCurrentMotor2 = 0;

// ============================================================
// UI STATE
// ============================================================
bool motorStopActive = true;          // M-stop is ON by default (motors disabled)

// Touch state (managed by touchInput.ino)
TouchState touchState = TOUCH_IDLE;
int16_t touchX = 0;                   // Mapped screen coordinates
int16_t touchY = 0;
int16_t rawTouchX = 0;                // Raw resistive values (for calibration)
int16_t rawTouchY = 0;
unsigned long lastTouchTime = 0;
bool tapDetected = false;             // Set on each new press, consumed by listeners

// Runtime touch calibration values (can be updated by calibration routine)
int tsMinX = TS_DEFAULT_MINX;
int tsMinY = TS_DEFAULT_MINY;
int tsMaxX = TS_DEFAULT_MAXX;
int tsMaxY = TS_DEFAULT_MAXY;

// Touch calibration state
TouchCalibState tCalState = TCAL_IDLE;
int tCalTarget = 0;                   // Which target we're on (0 to NUM_TARGETS-1)
int tCalRawX[TCAL_NUM_TARGETS];       // Recorded raw X for each target
int tCalRawY[TCAL_NUM_TARGETS];       // Recorded raw Y for each target

// Screen & button state (managed by screenManager.ino)
ScreenID currentScreen = SCREEN_HOME;
Button buttons[MAX_BUTTONS];
int buttonCount = 0;

// Telemetry display throttle
unsigned long lastDisplayUpdate = 0;

// ============================================================
// SETUP
// ============================================================
void setup() {
  Serial.begin(115200);   // Debug output (optional, remove for production)

  // Initialize display
  if (TFT_LITE >= 0) {
    pinMode(TFT_LITE, OUTPUT);
    analogWrite(TFT_LITE, 128);  // 50% brightness, adjust to taste
  }
  tft.begin();
  tft.setRotation(TFT_ROTATION);

  // Initialize radio
  radio.begin();
  radio.openWritingPipe(address);
  radio.setDataRate(RF24_250KBPS);
  radio.setPALevel(RF24_PA_MIN);
  radio.enableAckPayload();
  radio.setRetries(3, 5);

  // Default data values (64 = center/stopped for RoboClaw mixed mode)
  data.throttle = 64;
  data.steering = 64;
  data.data_motor_stop = true;

  // Draw initial screen
  changeScreen(SCREEN_HOME);
}

// ============================================================
// MAIN LOOP
// ============================================================
void loop() {
  // 1. Process touch input
  touchUpdate();

  // 2. Read joystick and set motor stop flag
  data.steering = readCalibratedInput(0);   // A0
  data.throttle = readCalibratedInput(1);   // A1
  data.data_motor_stop = motorStopActive;

  // 3. Transmit and receive acknowledge
  radio.write(&data, sizeof(dataPackage));
  if (radio.isAckPayloadAvailable()) {
    radio.read(&ack, sizeof(ackPackage));

    // Reconstitute 16-bit values from high/low bytes
    rawBatt = (ack.highBatt << 8) + ack.lowBatt;
    rawTemp1 = (ack.highTemp1 << 8) + ack.lowTemp1;
    rawTemp2 = (ack.highTemp2 << 8) + ack.lowTemp2;
    rawCurrentMotor1 = (ack.highIM1 << 8) + ack.lowIM1;
    rawCurrentMotor2 = (ack.highIM2 << 8) + ack.lowIM2;
  }

  // 4. Update current screen (throttled to avoid flicker)
  unsigned long now = millis();
  if (now - lastDisplayUpdate >= TELEMETRY_UPDATE_MS) {
    lastDisplayUpdate = now;
    screenUpdate();
  }
}

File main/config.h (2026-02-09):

#ifndef CONFIG_H
#define CONFIG_H

// ============================================================
// HARDWARE PIN ASSIGNMENTS
// !! Verify these match your physical wiring !!
//
// These defaults are from the pin assignment table (Sheet4).
// If your wiring matches the old test sketches instead,
// see the commented alternatives below each section.
// ============================================================

// --- nRF24L01 (default SPI bus) ---
#define CE_PIN    9
#define CSN_PIN   10

// --- ILI9341 Display (SPI1 bus) ---
// SPI1 pins: CLK=27, MISO=1, MOSI=26 (active when using &SPI1)
#define TFT_CS    0     // D0
#define TFT_DC    2     // D2
#define TFT_LITE  3     // D3, backlight

// --- Resistive Touchscreen ---
#define YP  A10   // D24, must be analog pin
#define XM  A11   // D25, must be analog pin
#define XP  28    // D28, digital
#define YM  29    // D29, digital

#define TS_RESISTANCE 314   // Ohms across X plate (measured with multimeter)

// --- Touch Calibration Defaults ---
// These are starting values. Runtime variables (tsMinX, etc.)
// can be updated by the touch calibration routine.
#define TS_DEFAULT_MINX   150
#define TS_DEFAULT_MINY   120
#define TS_DEFAULT_MAXX   920
#define TS_DEFAULT_MAXY   940
#define MINPRESSURE       10
#define MAXPRESSURE       1000

// --- Joystick ---
#define JOY_STEERING  A0    // D14
#define JOY_THROTTLE  A1    // D15

// --- Analog Input Calibration ---
// Generic calibration data per analog pin.
// Vehicle config maps pins to functions (e.g., A0 → steering).
#define NUM_ANALOG_INPUTS   2
#define ACAL_SAMPLES        10    // Number of reads to average per sample
#define ACAL_SAMPLE_DELAY   5     // ms between reads
#define ACAL_DEFAULT_DEADZONE 5   // Raw ADC units around center

struct AnalogCalData {
  uint8_t pin;            // Analog pin number
  long calCenter;         // Calibrated center (raw ADC average)
  long calMin;            // Calibrated min endpoint (raw ADC average)
  long calMax;            // Calibrated max endpoint (raw ADC average)
  byte deadZone;          // Dead zone around center (raw ADC units)
  bool calibrated;        // Has this input been through calibration?
};

enum AnalogCalStep {
  ACAL_IDLE,              // Not calibrating
  ACAL_CENTER,            // Waiting for user to position center
  ACAL_MIN,               // Waiting for user to position minimum
  ACAL_MAX,               // Waiting for user to position maximum
  ACAL_DONE               // Calibration complete, showing results
};

// ============================================================
// DISPLAY CONSTANTS
// ============================================================
#define SCREEN_W      240
#define SCREEN_H      320
#define TFT_ROTATION  2     // USB connector at top

// ============================================================
// CUSTOM COLORS (RGB565)
// ============================================================
#define SHADOW            0x2965
#define COLOR_STOP_RED    ILI9341_RED
#define COLOR_GO_GREEN    0x2DC6    // Slightly muted green

// ============================================================
// UI TIMING
// ============================================================
#define TOUCH_DEBOUNCE_MS     250   // Min ms between accepted presses
#define TELEMETRY_UPDATE_MS   100   // How often to refresh display values

// ============================================================
// SHARED TYPES
// These are defined here so all .ino files can see them
// (Arduino IDE concatenates .ino files alphabetically after main)
// ============================================================

// --- Touch State Machine ---
enum TouchState {
  TOUCH_IDLE,           // No touch detected
  TOUCH_PRESSED,        // Touch just detected this frame (fires once)
  TOUCH_HELD,           // Touch continuing from previous frame
  TOUCH_WAIT_RELEASE    // Waiting for finger lift before accepting new input
};

// --- Touch Calibration State ---
enum TouchCalibState {
  TCAL_IDLE,            // Not calibrating
  TCAL_WAIT_TARGET,     // Waiting for user to tap current target
  TCAL_DONE             // All targets collected, showing results
};

#define TCAL_NUM_TARGETS  3
// Target positions in screen pixels (where crosshairs are drawn)
// Spread across the screen for best calibration accuracy
#define TCAL_TARGET_0_X   20    // Near top-left (below header)
#define TCAL_TARGET_0_Y   60
#define TCAL_TARGET_1_X   220   // Near bottom-right (above back button)
#define TCAL_TARGET_1_Y   240
#define TCAL_TARGET_2_X   120   // Center (verification point)
#define TCAL_TARGET_2_Y   160

// --- Screen IDs ---
enum ScreenID {
  SCREEN_HOME,
  SCREEN_SETUP,
  SCREEN_CALIBRATE_TOUCH,
  SCREEN_CALIBRATE_THROTTLE,
  SCREEN_CALIBRATE_STEERING,
  SCREEN_COUNT
};
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

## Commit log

2020-08-17 Initial migration from Arduino IDE to PlatformIO/VS Code
2020-08-17 Add current 3D stl files and link to 3D design source
    [LCD Cover.stl, Thumb Panel.stl]
2020-08-25 Change pins for teensy 4.1
2020-08-28 Create Teensy 4.1 Pin Layout.pdf
2021-04-16 begin adding motor stop flags
2021-04-16 recreate Arduino version
2021-04-19 Create calibration.ino
    sketch to calibrate analog inputs with a mechanical return-to-center, such as a joystick.
2021-04-19 Update deadzone variables
    replace 'steering' and 'throttle' with 'wheel' and 'trigger'.
    [calibration.ino]
2026-02-08 reviving old project
    [pins.tsv]
2026-02-08 Revive project: restructure for Arduino IDE, add touchscreen UI framework
    Port from PlatformIO/VS Code to Arduino IDE multi-file project structure.
    Replace single main.cpp with modular .ino files:
    - main.ino: setup, loop, radio, global state
    - config.h: pin assignments, constants, shared types
    - touchInput.ino: resistive touch state machine with ghost-press prevention
    - screenManager.ino: screen transitions, button registration, hit testing
    - drawScreens.ino: screen drawing and per-frame UI updates
    [pins.tsv]
2026-02-09 incorporate new calibration routines
2026-02-16 Update .gitignore
    add kicad exclusions
2026-02-16 Add button board pcb project
    [Dual Button PCB.kicad_pcb, Dual Button PCB.kicad_sch]
2026-02-16 Start main pcb design
    [Transmitter Main Board.kicad_pcb, Transmitter Main Board.kicad_sch, button_matrix.kicad_sch]
2026-02-17 files saved in the wrong directory
    [Transmitter Main Board.kicad_pcb, Transmitter Main Board.kicad_sch, button_matrix.kicad_sch]
2026-02-17 Create 4960 symbol and footprint
    [Transmitter Main Board.kicad_pcb, Transmitter Main Board.kicad_sch, button_matrix.kicad_sch]
2026-02-20 Python script to locate leds in relation to their switches.
2026-02-20 more routing
    [Transmitter Main Board.kicad_pcb, Transmitter Main Board.kicad_sch]
2026-02-21 more more more routing
    [Transmitter Main Board.kicad_pcb, Transmitter Main Board.kicad_sch, button_matrix.kicad_sch]
2026-02-21 finalish routing
    [Transmitter Main Board.kicad_pcb, Transmitter Main Board.kicad_sch]
2026-02-22 Final final routing
    [Transmitter Main Board.kicad_pcb, Transmitter Main Board.kicad_sch]
2026-02-22 begin overcomplication
    [Transmitter Main Board.kicad_pcb, Transmitter Main Board.kicad_sch]
